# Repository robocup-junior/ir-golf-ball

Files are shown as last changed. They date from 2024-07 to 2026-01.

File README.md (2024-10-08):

# IR golf ball

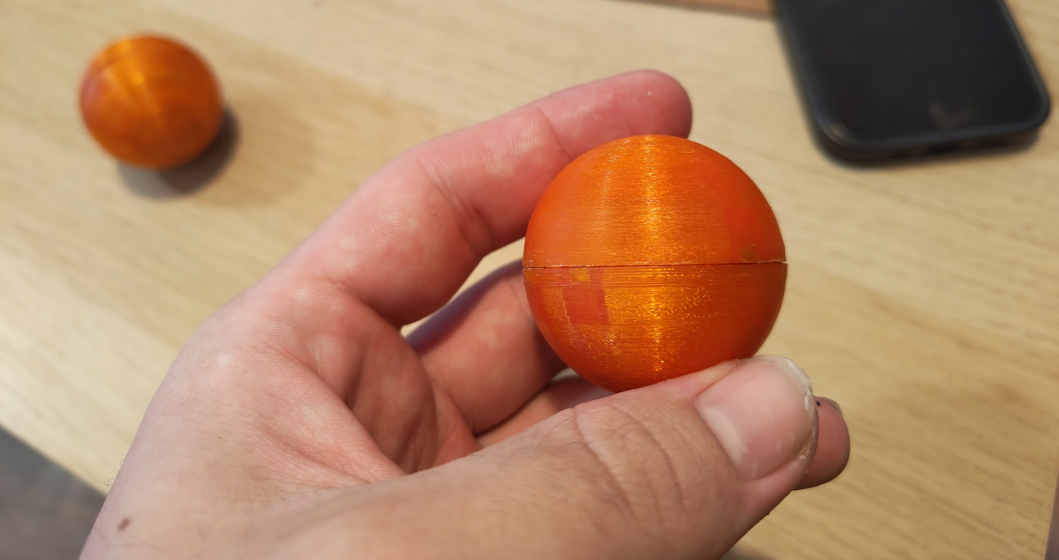
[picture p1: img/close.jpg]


# What / Why it is?
A golf size ball emiting IR light powered by 18350 Li-Ion battery with 40khz modulation (8 pulzes of 40khz then off with period of 1.2khz)

# How to get it?

## Buy it and suport us
You will be able to buy it soon from many places, for now we are taking preorders [here](https://docs.google.com/forms/d/e/1FAIpQLSeDNluafNvnX1WBIk5zJzcXsfOrKENFUOebmqeOT6po7Bbjzg/viewform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) cost is 20$ per ball build without battery

## Make it your self
## Step 1: Get all materials
You will be able to order kit from us or you can source all neaded components by your self.
### 1. Flex PCB
We recomend to order flexPCB from eather JLCPCB or PCBWAY, both do have sponsorship programs so you might be able to get it for free. Depending on your buget and skill set also think about ordering stencil (all componentc are posible to solder by hand soledring but it is easier to do it with stencil)

https://www.pcbway.com/sponsor.html
https://jlcpcb.com/help/article/how-to-apply-for-free-pcb
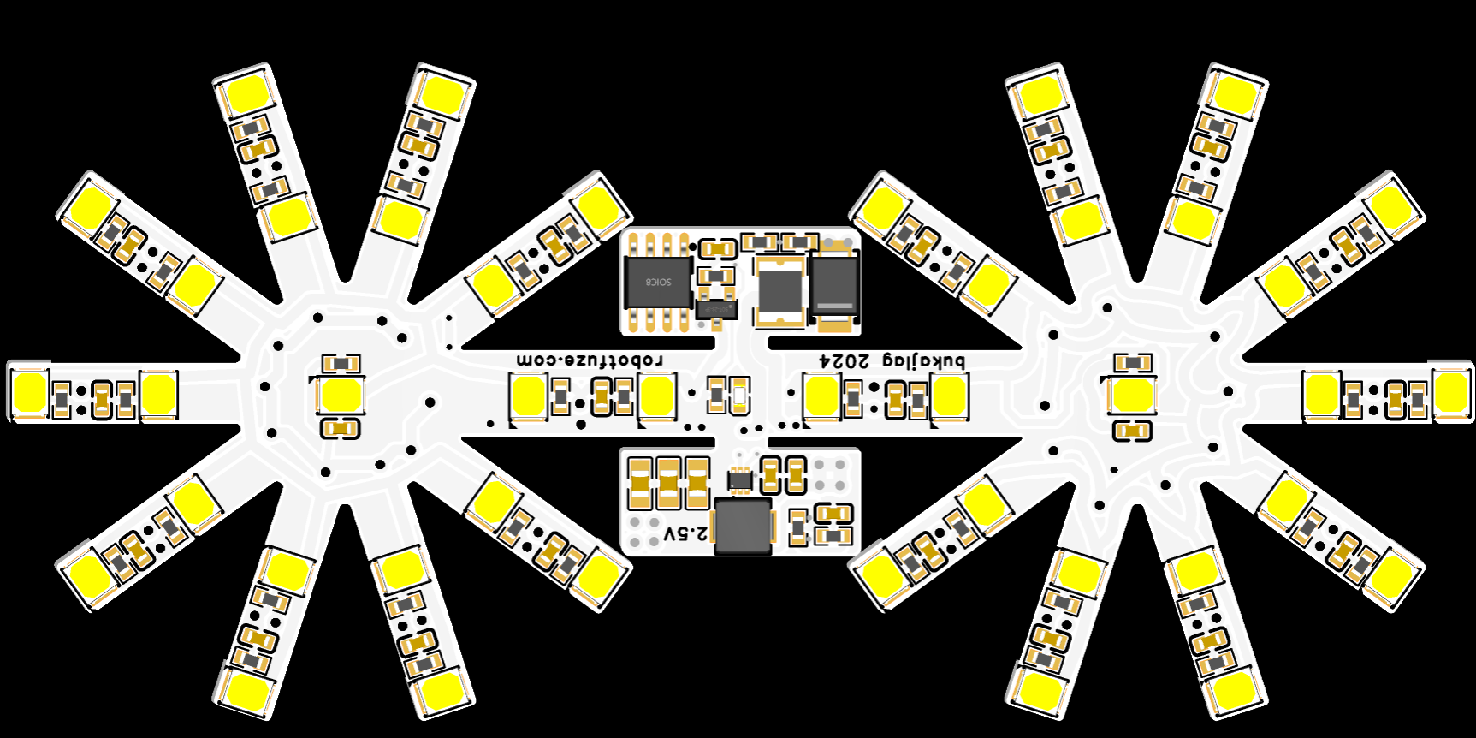
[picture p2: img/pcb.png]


All gerber files are in this repo.

### 2. Electrical components
<table>
  <thead>
    <tr>
      <th>Image</th>
      <th>Quantity</th>
      <th>Comment</th>
      <th>Footprint</th>
      <th>Value</th>
      <th>Manufacturer Part</th>
    </tr>
  </thead>
  <tbody>
    <tr>
      <td></td>
      <td>24</td>
      <td>22uF</td>
      <td>C0603</td>
      <td>22uF</td>
      <td>GRM188R60J226MEA0D</td>
    </tr>
    <tr>
      <td></td>
      <td>3</td>
      <td>47uF</td>
      <td>C0805</td>
      <td>47uF</td>
      <td>C2012X5R1A476MTJ00E</td>
    </tr>
    <tr>
      <td></td>
      <td>1</td>
      <td>4.7nF</td>
      <td>C0603</td>
      <td>4.7nF</td>
      <td>CC0603KRX7R9BB472</td>
    </tr>
    <tr>
      <td></td>
      <td>1</td>
      <td>120pF</td>
      <td>C0603</td>
      <td>120pF</td>
      <td>CL10C121JB8NNNC</td>
    </tr>
    <tr>
      <td></td>
      <td>1</td>
      <td>SS1045-SMB</td>
      <td>SMB_L4.4-W3.6-LS5.3-RD</td>
      <td></td>
      <td>SS1045-SMB</td>
    </tr>
    <tr>
      <td></td>
      <td>1</td>
      <td>220nH</td>
      <td>IND-SMD_L4.1-W4.1</td>
      <td>220nH</td>
      <td>IHLP1616BZERR22M01</td>
    </tr>
    <tr>
      <td></td>
      <td>42</td>
      <td>XL-2835IR-T202</td>
      <td>SMD2835</td>
      <td></td>
      <td>XL-2835IR-T202</td>
    </tr>
    <tr>
      <td></td>
      <td>1</td>
      <td>XL-1608SURC-06</td>
      <td>LED0603</td>
      <td></td>
      <td>XL-1608SURC-06</td>
    </tr>
    <tr>
      <td></td>
      <td>1</td>
      <td>AP3404</td>
      <td>SOT-23-3</td>
      <td></td>
      <td>AP3404</td>
    </tr>
    <tr>
      <td></td>
      <td>42</td>
      <td>10Ω</td>
      <td>R0603</td>
      <td>10Ω</td>
      <td>0603WAF100JT5E</td>
    </tr>
    <tr>
      <td></td>
      <td>3</td>
      <td>10k</td>
      <td>R0603</td>
      <td>10k</td>
      <td>RC0603FR-0710KL</td>
    </tr>
    <tr>
      <td></td>
      <td>1</td>
      <td>316kΩ</td>
      <td>R0603</td>
      <td>316kΩ</td>
      <td>RC0603FR-07316KL</td>
    </tr>
    <tr>
      <td></td>
      <td>1</td>
      <td>100kΩ</td>
      <td>R0603</td>
      <td>100kΩ</td>
      <td>RC0603FR-07100KL</td>
    </tr>
    <tr>
      <td></td>
      <td>1</td>
      <td>100Ω</td>
      <td>R0603</td>
      <td>100Ω</td>
      <td>0603WAJ0101T5E</td>
    </tr>
    <tr>
      <td></td>
      <td>1</td>
      <td>ATTINY202-SSNR</td>
      <td>SOIC-8</td>
      <td></td>
      <td>ATTINY202-SSNR</td>
    </tr>
    <tr>
      <td></td>
      <td>1</td>
      <td>TPS62A06DRLR</td>
      <td>SOT-563-6</td>
      <td></td>
      <td>TPS62A06DRLR</td>
    </tr>
    <tr>
      <td></td>
      <td>1</td>
      <td>1812L400/12GR</td>
      <td>F1812</td>
      <td></td>
      <td>1812L400/12GR</td>
    </tr>
  </tbody>
</table>

We recomend ordering from LCSC but you can find all the componets on other sites as well (Mouser,Digikey...). For finding best suplier for you, we recomend using https://octopart.com/ and checking out list of eqvivalent componts (TODO list of eqvivalent components and selection criterias)

### 3. Mechanical components
#### Filament
Shells are 3D printed, after lot of testing we found out that best option in general is using [PCTG](https://shop.spectrumfilaments.com/product-eng-1414-Filament-Spectrum-Premium-PCTG-1-75mm-PURE-ORANGE-1kg-RAL-2004.html) for good optical properties/cheap/easy to print/mechanical properties similar to PC. But PC is also posible to use.

#### Magnets
For magnets we are using 6 [6mm*5mm](https://www.unimagnet.cz/neodymovy-magnet-kotouc-6-mm-v-5-mm-sila-1-2-kg_z323/) N42 neodimium magnets. 

#### Brass 
For ball balancing we are using 6mm brass rod cuted into 6*5mm peaceas. We chose brass rod because it is really easy to find and it is cheap it has high density and it is not toxick.

#### Glue
Any superglue will work fine

### 4. Battery
We are using 18350 Li-Ion battery. We recomend capacity ranging from 1100mAh to 1200mAh (for balance reasons). It schold be easy to find in your local vape shop or battery store. Dont forget to get charger if you dont have one.

## Step 2: Print 3D shells
You can find stl files as well as sliced model in prushaslicer in 3d in this repo. Main thing to look for is to use enought of separation distance for suports (0.35mm) and to set temperature of bad to 100 C and nozle to 250 C.
Also print counterwight for balance and fill it with solder.

## Step 3: Asemble PCBs
While your 3d printer is working you can asemble PCBs. It can be done by hand but stencil is more convinient. We recomend to place coil as last component so you will be able to rework regulator solder joints if neaded after reflow.
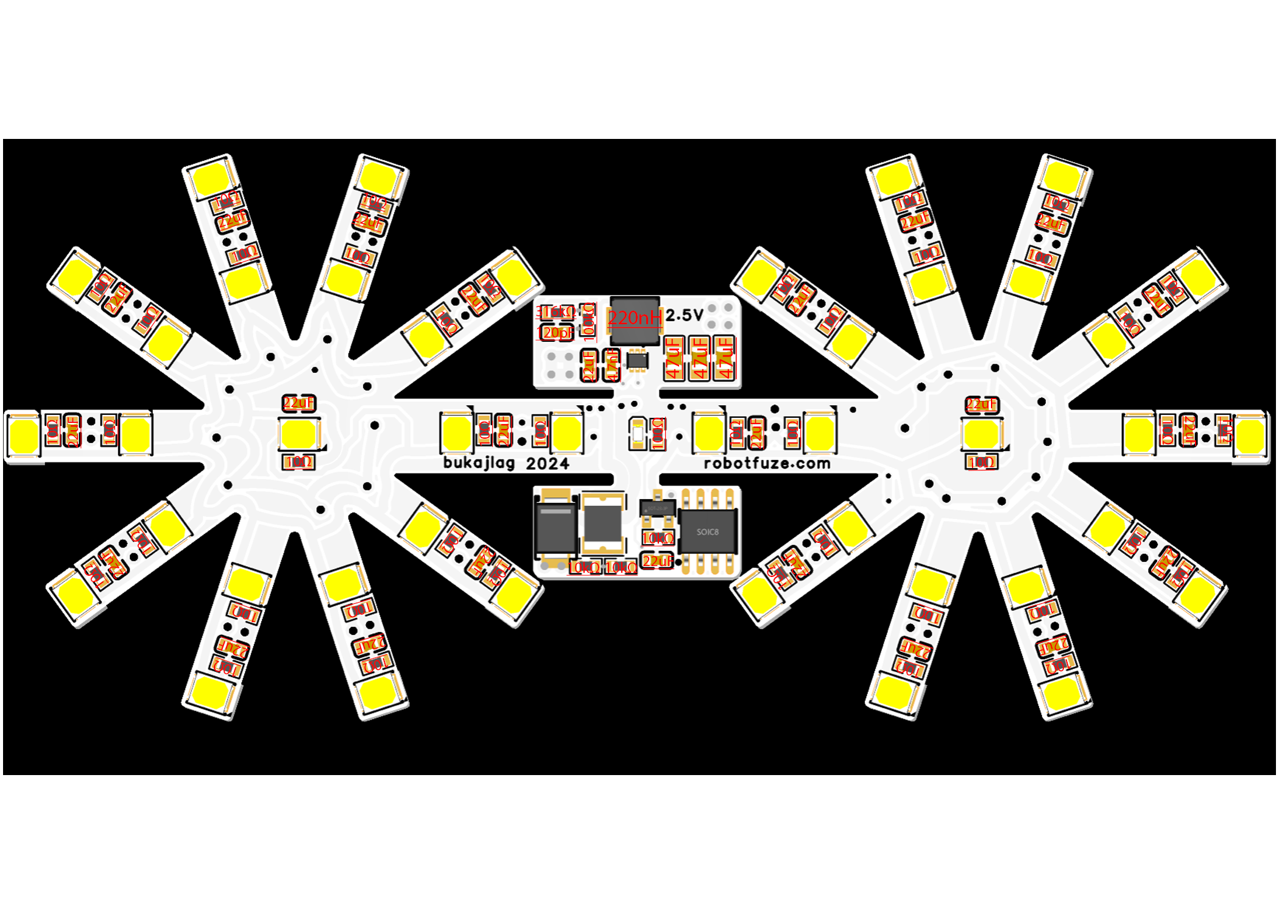
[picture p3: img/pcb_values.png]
pcb_values


## Step 4: Program AtTiny
This step is not neaded when you did buy a kit from us. 
The best way to aproach this is to watch this video: https://www.youtube.com/watch?v=AL9vK_xMt4E
and upload code as mention in the video. Dont forget to contect 3.3V to 2.5V trace when programing so UDPI voltages do match.

Also you schold test your PCB by using baterry if all LEDs are on.
TODO make video how to do it for our PCB

## Step 5: Cut brass rod
Now you nead to cut that 6mm btass rod into 5mm pieces, you will nead 12 of them. 

## Step 6: Insert magnets and brass rods into shells
Now you will nead to insert magnets and brass rods into 3D printed shells and glue it in using superglue. And wait till it will dry.

## Step 7: Insert PCB
Insert PCB into a 3D printed schells and make shure that baterry fits corectly. You can regulate contact of batery with PCB by adding or removing solder from battery contact pads that are on the PCB.

## Step 8: Test
Test your ball if it glows using your mobile phone.
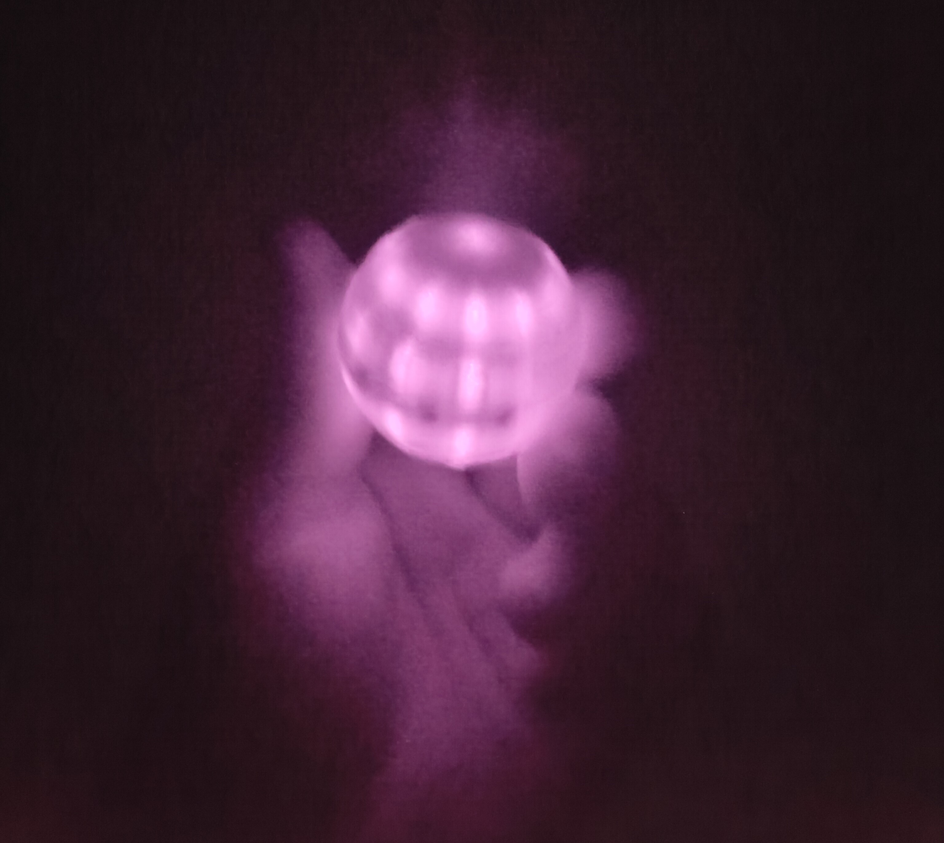
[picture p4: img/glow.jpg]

The end (:

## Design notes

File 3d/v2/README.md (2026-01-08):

# IR-Golf-Ball 3D Model v2

## What's Changed?
- You can assemble it without superglue!
- Easy battery change. The inner weight stays in the core when you take off one of the shells. 
- Uses M5x16mm set screws for counter weight. Easy procurement. 
- Calculated balance on CAD

## Parts List

| Item | Material | QTY | Note |
|---|---|---|---|
| Spacer M2x10mm | SUS304 | 2 | |
| M2x16mm Self-Tapping Screw | Carbon Steel | 2 | |
| M2x10mm Hex Socket Cap Screw (DIN912) | SUS304 | 4 | |
| 4mm Metal Ball | SUS304 | 26 | |
| M5x16mm Set Screw (DIN916) | SUS304 | 2 | |
| PCB | N/A | 1 | No Change from v1 |
| LiPo Cell 18360 | N/A | 1 | No Change from v1 |
| 3D Printed Ball Shell | PCTG | 2 | No Change from v1 |
| 3D Printed Inner Weight | PCTG/PETG | 2 | |
| 3D Printed Counter Weight | PCTG/PETG | 1 | |

## How to Assemble 
*Only explains differences from v1. Please follow v1 assembly instructions for the rest

### Counter Weight
Insert two M5x16mm set screws into the 3D-printed counter weight from each side.
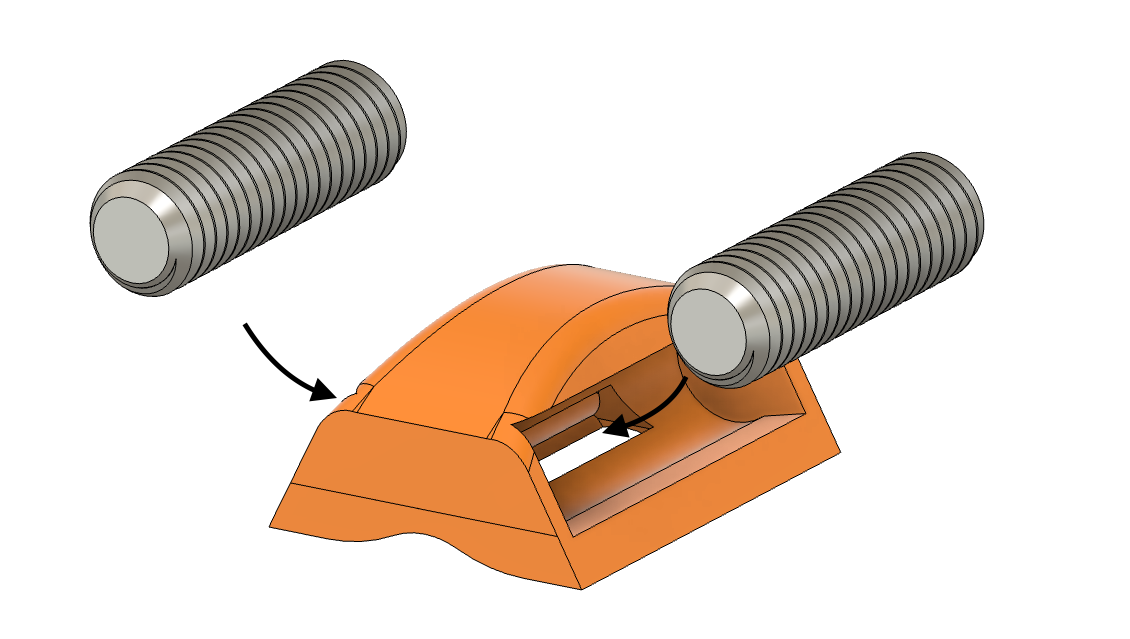
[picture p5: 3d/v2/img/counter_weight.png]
Assemblying Counter Weight


### Inner Weight
Place 4mm metal balls on the 3D-printed inner weight and gently push them into the holes one by one. Some holes require two balls in a row. Repeat for both inner weights.
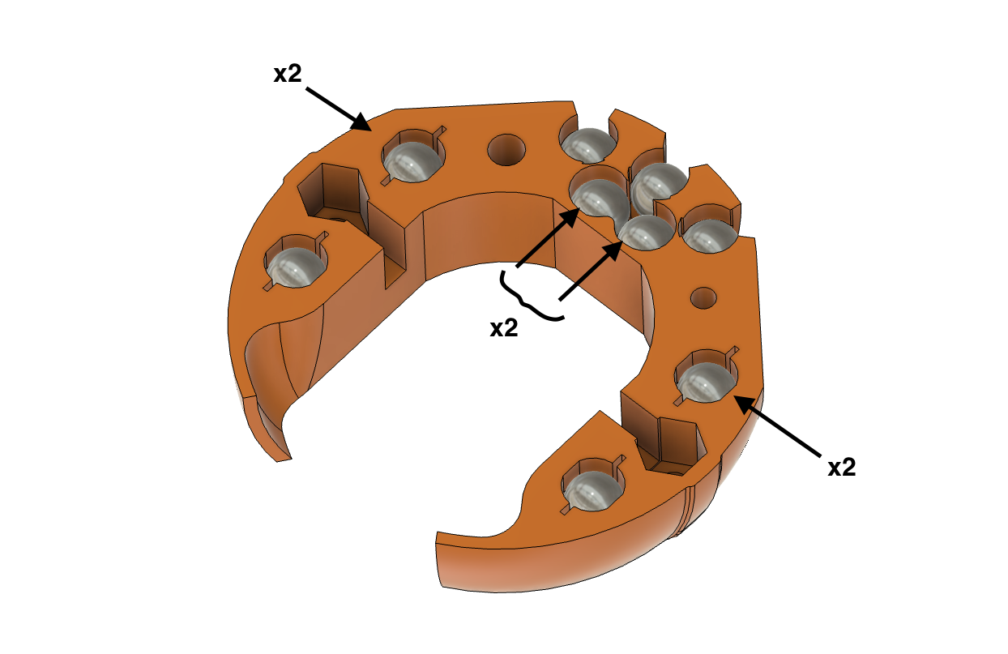
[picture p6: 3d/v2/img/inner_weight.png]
Insert balls into inner weight

  
Place two 2mm spacers on one of the inner weights and put the other one on top. Fix them with two M2 self-tapping screws. 
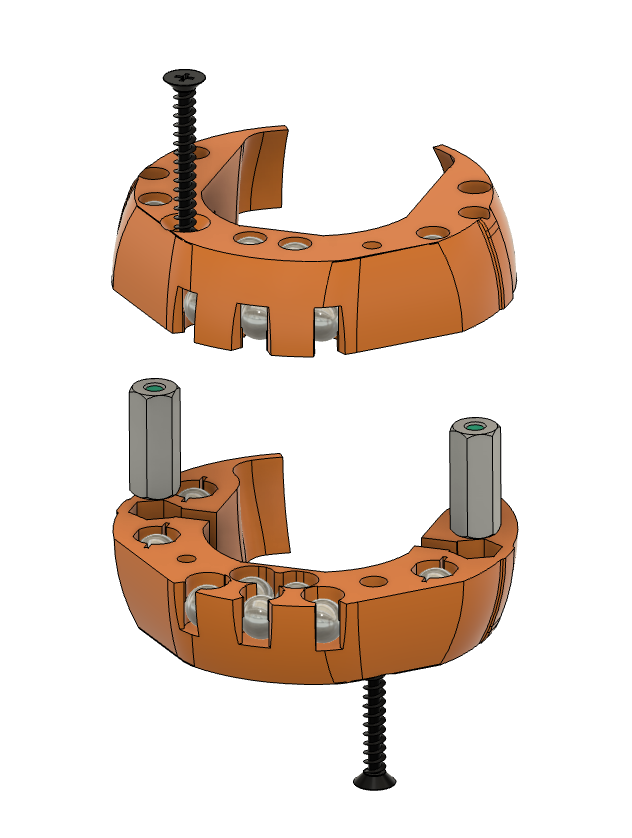
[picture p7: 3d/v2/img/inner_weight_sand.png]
Assembly inner weight


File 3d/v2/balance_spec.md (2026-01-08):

# IR Ball v2 Balance Report

### Basic Properties

| Property | Value |
|---|---|
| Mass | 57.950 g |
| Center of Mass | (0.007, -0.004, -0.386) mm |
| CoM Eccentricity | 0.386 mm |

### Inertia Tensor at Center of Mass (g·mm²)

$$
\mathbf{I}_{CM} = \begin{pmatrix}
8869.184 & 0.440 & -4.100 \\
0.440 & 8864.378 & 2.508 \\
-4.100 & 2.508 & 8816.923
\end{pmatrix}
$$

### Principal Moments of Inertia

| Principal Axis | Value (g·mm²) |
|---|---|
| I₁ (min) | 8816.469 |
| I₂ (mid) | 8864.500 |
| I₃ (max) | 8869.516 |

### Quality Metrics

| Metric | Value |
|---|---|
| Moment Difference (I₃/I₁ - 1) | 0.60% |
| Spread (I₃ - I₁) | 53.0 g·mm² |

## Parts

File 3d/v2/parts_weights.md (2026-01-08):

To calculate the balance of the ball, here is the list of part weights measured with actual parts.

# Parts Weights
| Item | Material | Mass | Note |
|---|---|---|---|
| Spacer M2x10mm | SUS304 | 0.841g | |
| M2x16mm Self-Tapping Screw | Carbon Steel | 0.239g | |
| M2x10mm Hex Socket Cap Screw (DIN912) | SUS304 | 0.285g | |
| 4mm Metal Ball | SUS304 | 0.253g | Diameter was 3.97mm |
| M5x16mm Set Screw (DIN916) | SUS304 | 1.63g  | |
| PCB | N/A | | Battery terminals soldered |
| LiPo Cell 18360 | N/A | | Vapcell 18350 M11 V2.0 1100mAh |
| 3D Printed Ball Shell* | PCTG | 5.90g  | |
| 3D Printed Inner Weight* | PCTG/PETG | 3.00g  | |
| 3D Printed Counter Weight* | PCTG/PETG | 0.78g  | |

# Weight Measurement Methodology

Randomly pick 10 pieces of an item from a bag and measure with a calibrated precision scale. Divide the measured weight by 10. Repeat the procedure with the remaining parts 5–15 times depending on the total quantity, then remove the minimum and maximum values and take the median of the rest. Use 3 significant figures.

__Weight scale__: Vibra DJ-150 (Minimum unit: 0.01g, calibrated with calibration weights)

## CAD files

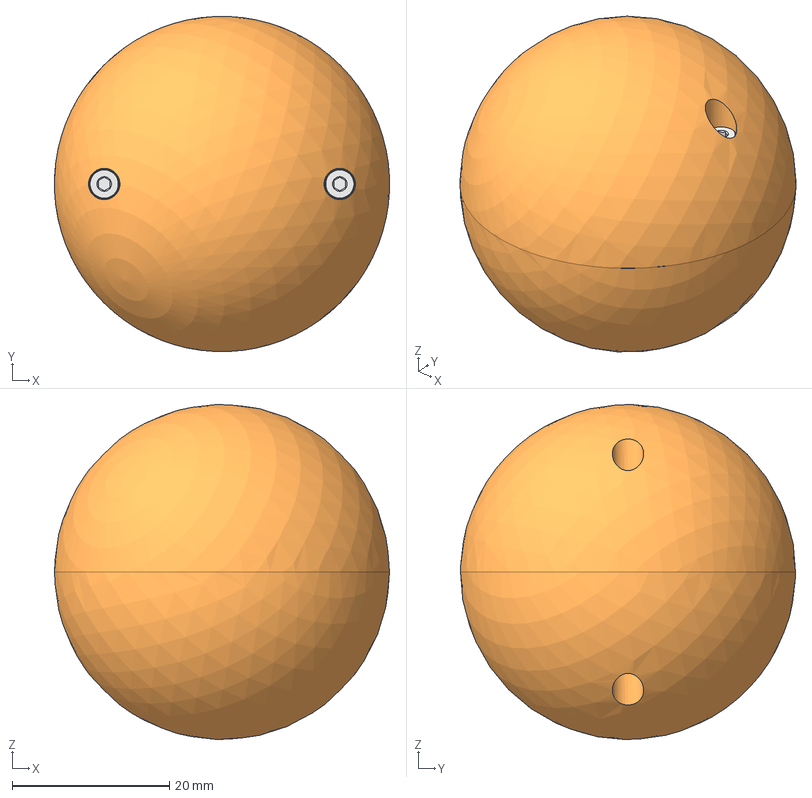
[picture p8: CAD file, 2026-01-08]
3d/v2/Assembly_v2.step
42.7 x 42.7 x 42.7 mm
shell_2025 v94 (1)_shell x 2
96415K57_Corrosion-Resistant 316 Stainless Steel Ball x 26
91290A017_Alloy Steel Socket Head Screw x 4
Board
Board (1)
92605A239_Stainless Steel Flat-Tip Set Screw x 2
90485A417_Stainless Steel Flat Head Thread-Forming Screws for Plastic x 2

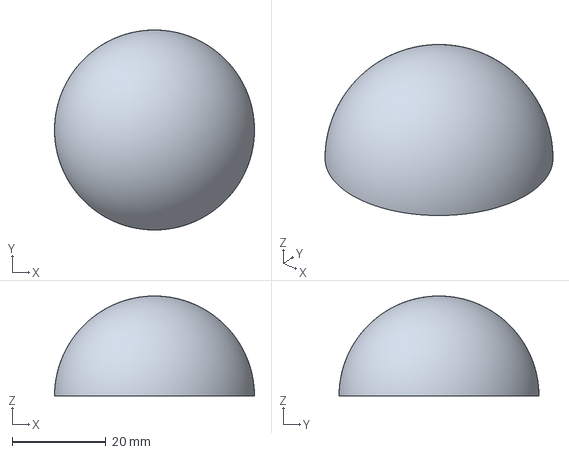
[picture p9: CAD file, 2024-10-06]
3d/ir_golf_ball.3mf
42.7 x 42.7 x 21.3 mm

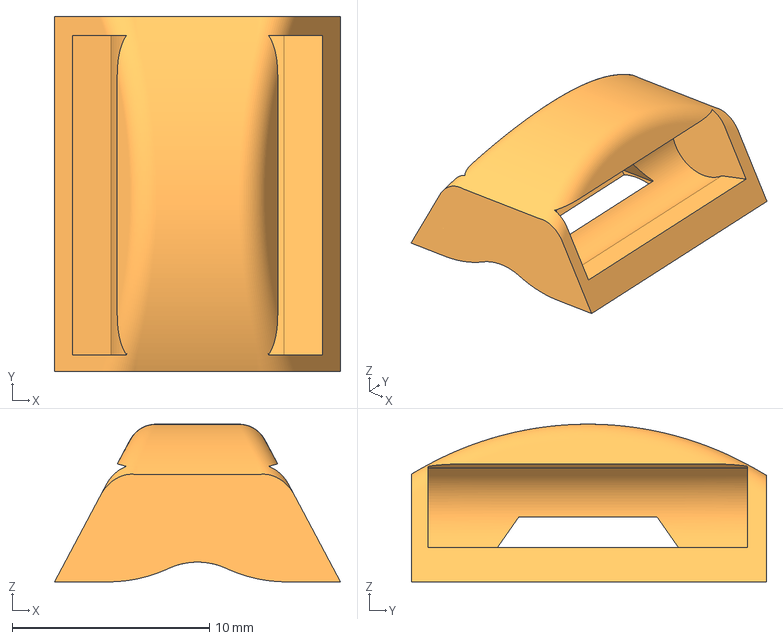
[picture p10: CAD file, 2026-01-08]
3d/v2/Counter_weight_v2.3mf
14.5 x 18.0 x 8.00 mm

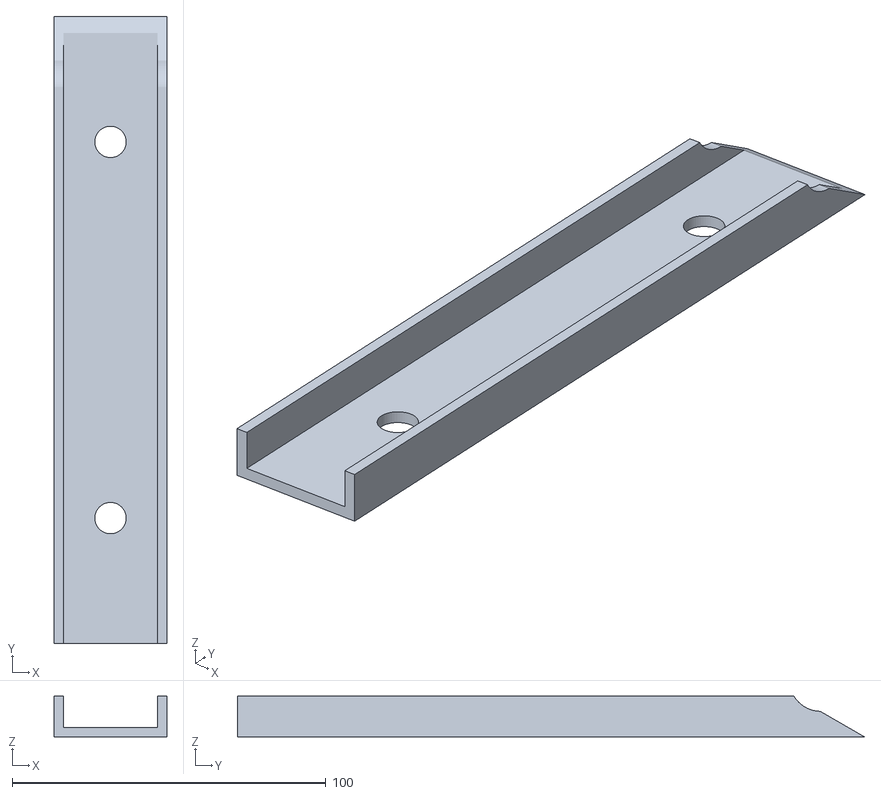
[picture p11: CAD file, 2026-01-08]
balance_evaluation/slope_top.stl
36.0 x 200.0 x 13.0

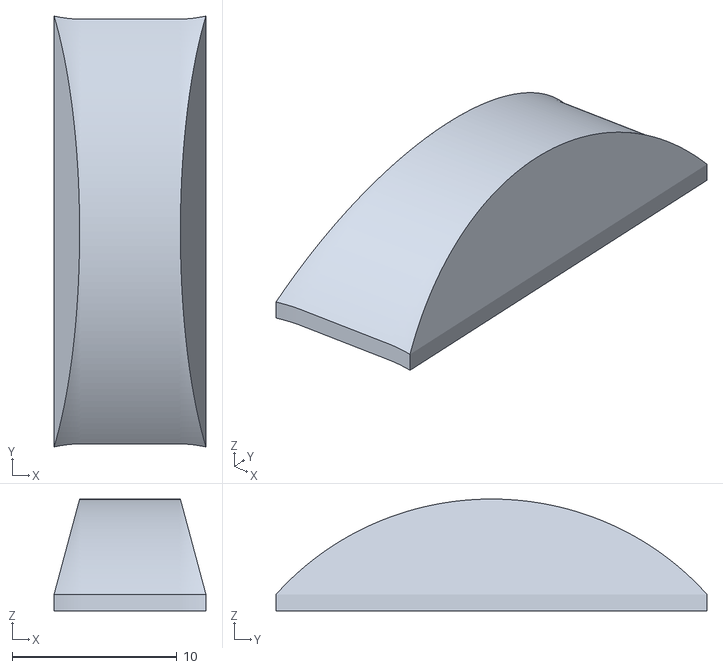
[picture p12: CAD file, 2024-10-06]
3d/balance.stl
9.23 x 26.2 x 6.80

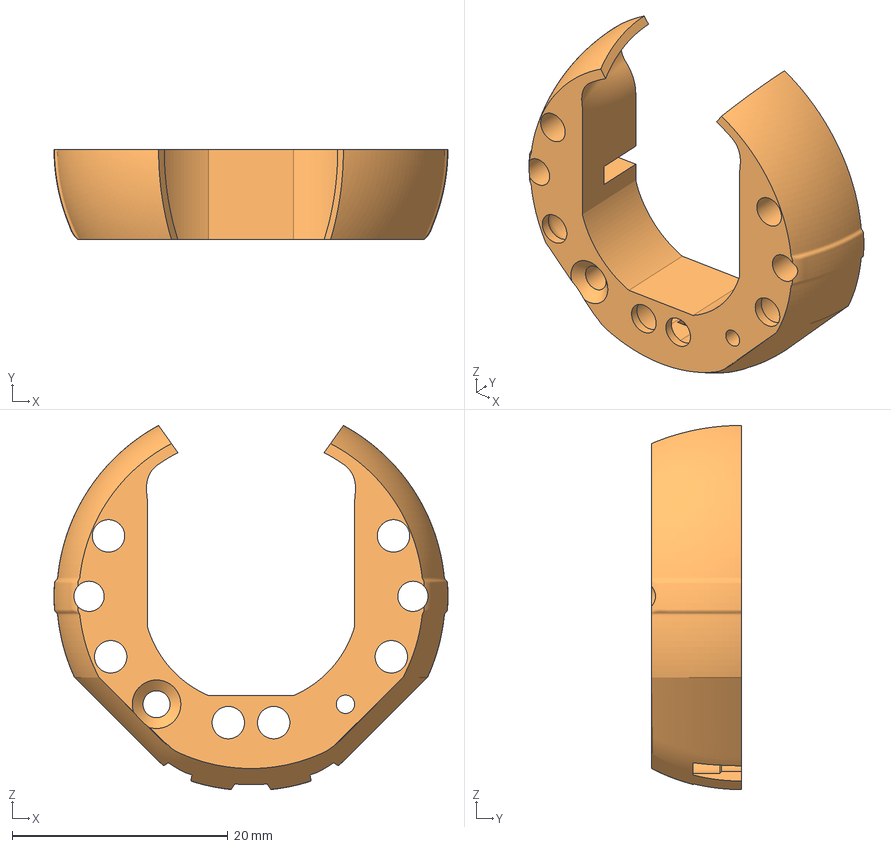
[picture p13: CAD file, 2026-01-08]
3d/v2/inner_weight_v2.3mf
36.5 x 8.34 x 33.7 mm

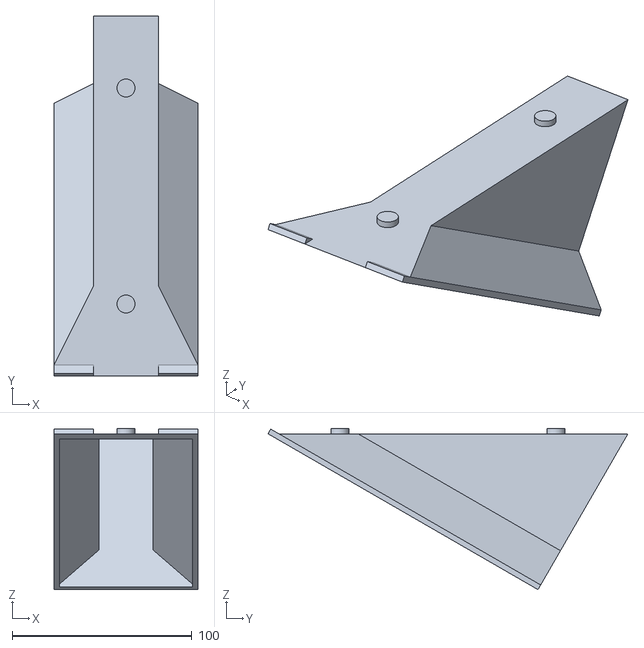
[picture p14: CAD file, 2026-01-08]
balance_evaluation/slope_base.stl
80.0 x 200.0 x 89.6

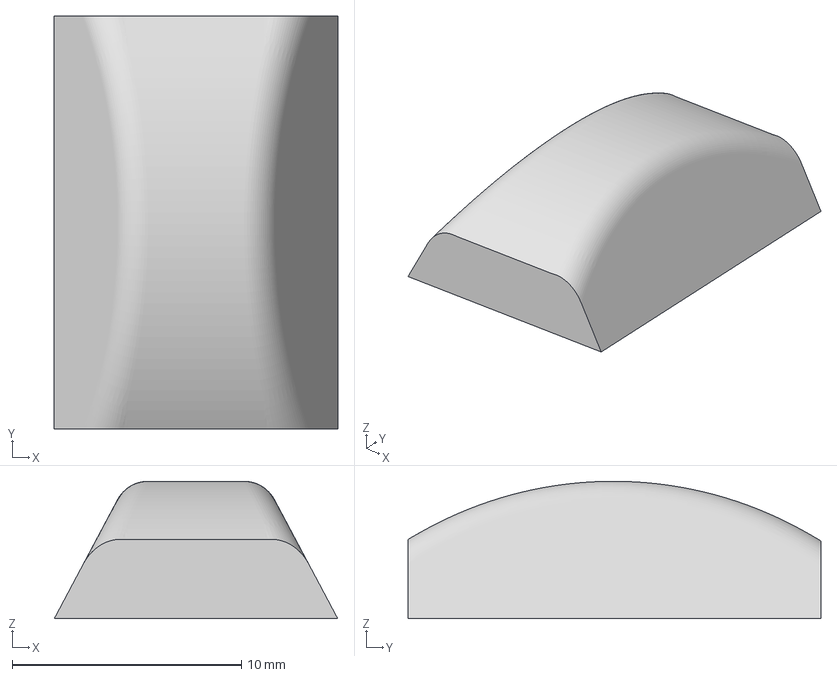
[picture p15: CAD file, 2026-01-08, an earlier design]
3d/v1/Counter_weight.3mf
12.4 x 18.0 x 6.00 mm

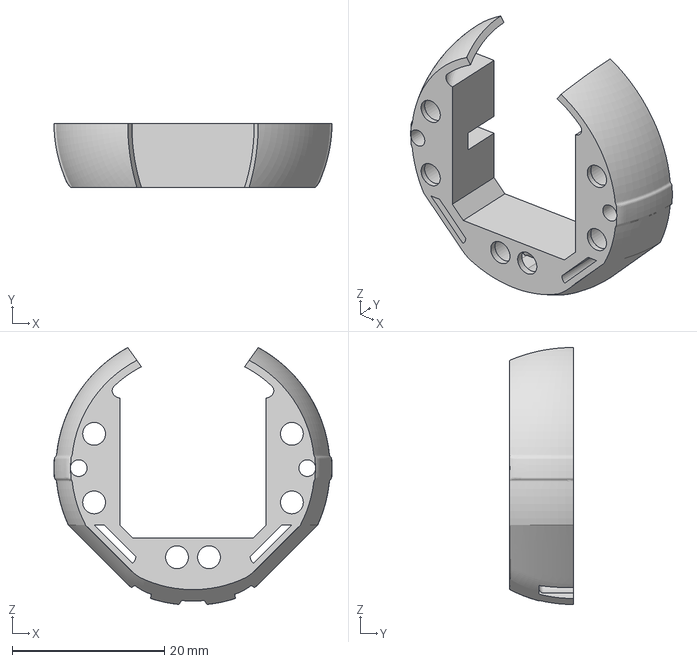
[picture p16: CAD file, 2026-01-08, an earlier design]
3d/v1/iner_screws.3mf
36.5 x 8.34 x 33.7 mm

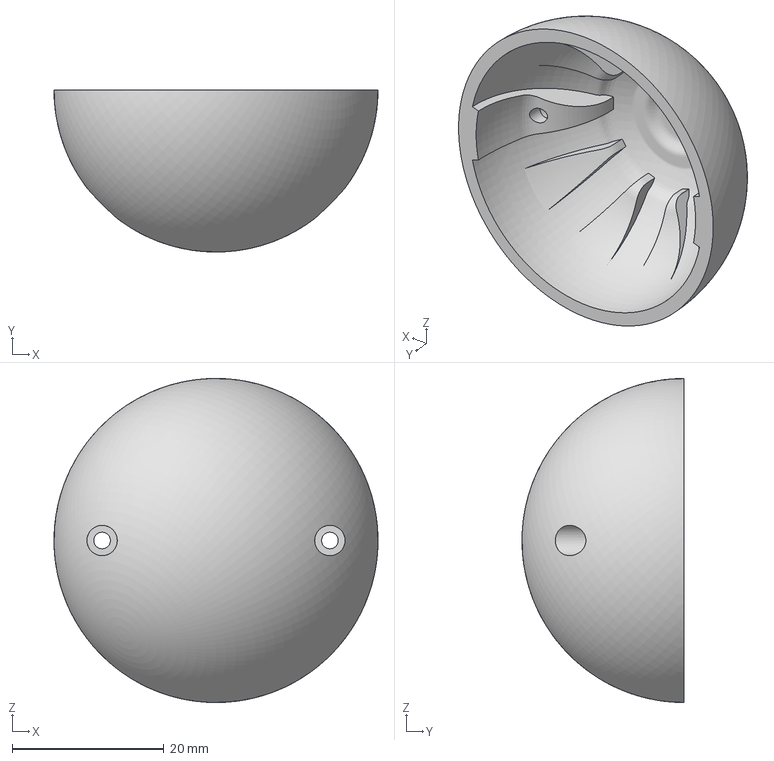
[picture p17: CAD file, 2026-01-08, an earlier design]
3d/v1/shell_screws.3mf
42.7 x 21.3 x 42.7 mm

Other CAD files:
3d/ir_golf_ball.stl

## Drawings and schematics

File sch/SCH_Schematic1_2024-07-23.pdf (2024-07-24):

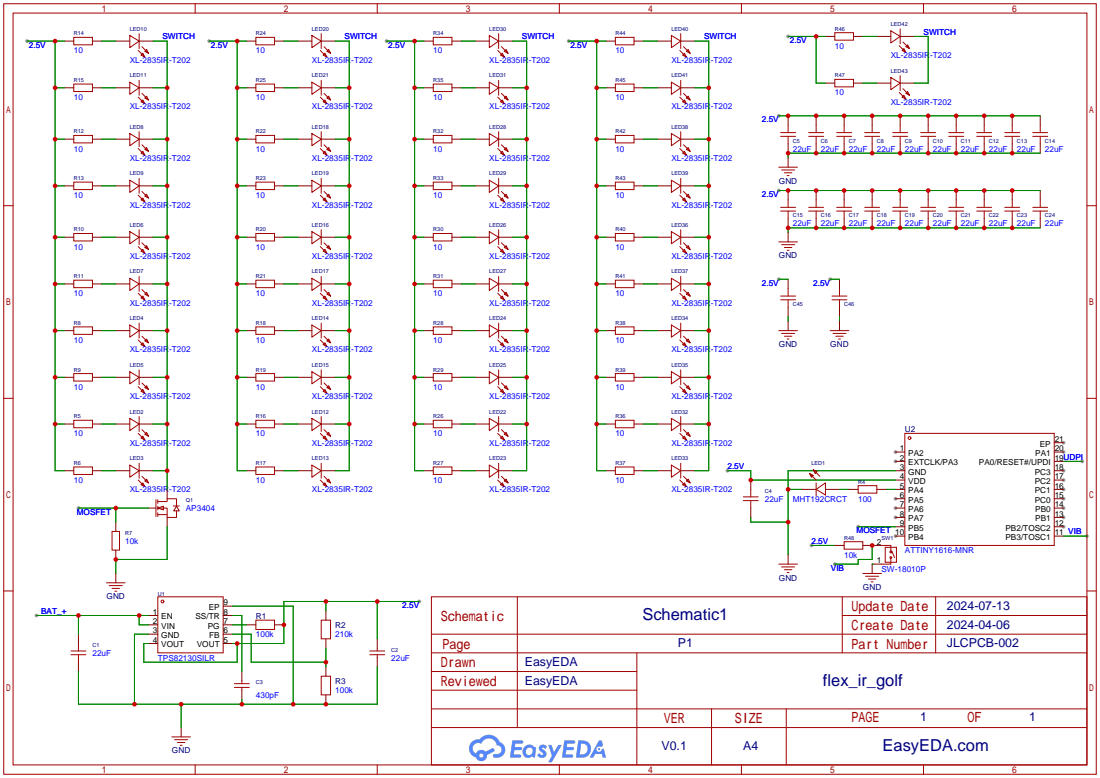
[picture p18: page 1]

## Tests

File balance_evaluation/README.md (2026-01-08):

# How to Measure the Balance: Deriving Principal Moments of Inertia from Inertia Tensor

The balance of the ball is important since if it's not balanced, the ball does not roll straight. 
In this document, we discuss how to evaluate the balance of the ball from logical and physical perspectives. 

As preparation, measure the weight of each part and set the density based on the volume of objects in Autodesk Fusion. 
By left-clicking on Project -> Properties, you can see the inertia tensor as `Moment of Inertia at Center of Mass (g mm^2)`

The inertia tensor of a rigid body is represented as a 3×3 symmetric matrix:

$$
\mathbf{I} = \begin{pmatrix}
I_{xx} & I_{xy} & I_{xz} \\
I_{xy} & I_{yy} & I_{yz} \\
I_{xz} & I_{yz} & I_{zz}
\end{pmatrix}
$$

Where:
- **Diagonal components** $I_{xx}, I_{yy}, I_{zz}$: Moments of inertia about each axis
- **Off-diagonal components** $I_{xy}, I_{xz}, I_{yz}$: Products of inertia

## 2. Principal Moments of Inertia (Eigenvalue Problem)

The principal moments of inertia $I_1, I_2, I_3$ are obtained as the **eigenvalues** of the inertia tensor.

Eigenvalue equation:

$$
\det(\mathbf{I} - \lambda \mathbf{E}) = 0
$$

Expanding yields the **characteristic equation** (cubic equation):

$$
\lambda^3 - \text{tr}(\mathbf{I})\lambda^2 + \frac{1}{2}\left[(\text{tr}\mathbf{I})^2 - \text{tr}(\mathbf{I}^2)\right]\lambda - \det(\mathbf{I}) = 0
$$

Or more explicitly:

$$
\begin{vmatrix}
I_{xx} - \lambda & I_{xy} & I_{xz} \\
I_{xy} & I_{yy} - \lambda & I_{yz} \\
I_{xz} & I_{yz} & I_{zz} - \lambda
\end{vmatrix} = 0
$$

The three real roots $\lambda_1, \lambda_2, \lambda_3$ of this cubic equation are the principal moments of inertia:

$$
I_1 = \lambda_{\min}, \quad I_2 = \lambda_{\text{mid}}, \quad I_3 = \lambda_{\max}
$$

## 3. Coefficients of the Characteristic Equation

The characteristic equation can be written as:

$$
\lambda^3 - A\lambda^2 + B\lambda - C = 0
$$

Where:

$$
A = I_{xx} + I_{yy} + I_{zz} = \text{tr}(\mathbf{I})
$$

$$
B = I_{xx}I_{yy} + I_{yy}I_{zz} + I_{zz}I_{xx} - I_{xy}^2 - I_{yz}^2 - I_{xz}^2
$$

$$
C = \det(\mathbf{I})
$$

## 4. Principal Moment Difference (Isotropy Metrics)

Once the principal moments are obtained, the deviation from spherical symmetry can be evaluated using the following metrics:

### 4.1 Moment Difference

$$
\varepsilon = \frac{I_{\max} - I_{\min}}{I_{\min}} \times 100\%
$$

Or equivalently:

$$
\varepsilon = \left(\frac{I_3}{I_1} - 1\right) \times 100\%
$$

**This Moment Difference should be as small as possible!**  
**Less difference means more equality of inertia on each axis, which makes the ball roll straighter!!**

### 4.2 Spread

$$
\Delta I = I_{\max} - I_{\min} = I_3 - I_1
$$

## (Reference) 5. Perfect Sphere Case

For a homogeneous perfect sphere:

$$
I_1 = I_2 = I_3 = \frac{2}{5}mr^2
$$

In this case:
- Moment difference $\varepsilon = 0\%$
- Spread $\Delta I = 0$
- The inertia tensor is diagonal (all off-diagonal components are zero)

## 6. Numerical Example
Let us calculate the Principal Moments of Inertia and Moment Difference by using the inertia tensor from v2 model.  

Input data:

$$
\mathbf{I}_{CM} = \begin{pmatrix}
8869.184 & 0.440 & -4.100 \\
0.440 & 8864.378 & 2.508 \\
-4.100 & 2.508 & 8816.923
\end{pmatrix}
$$

Eigenvalue calculation results:

| Principal Moment | Value (g·mm²) |
|---|---|
| $I_1$ (min) | 8816.469 |
| $I_2$ (mid) | 8864.500 |
| $I_3$ (max) | 8869.516 |

Moment difference:

$$
\varepsilon = \left(\frac{8869.516}{8816.469} - 1\right) \times 100\% = 0.60\%
$$

# Test the Balance in Real Environment
In addition to the logic above, evaluating the balance of the assembled ball in your hand is also important.

## Preparation
Print this model with your 3D printer. Any type of filament is fine. 
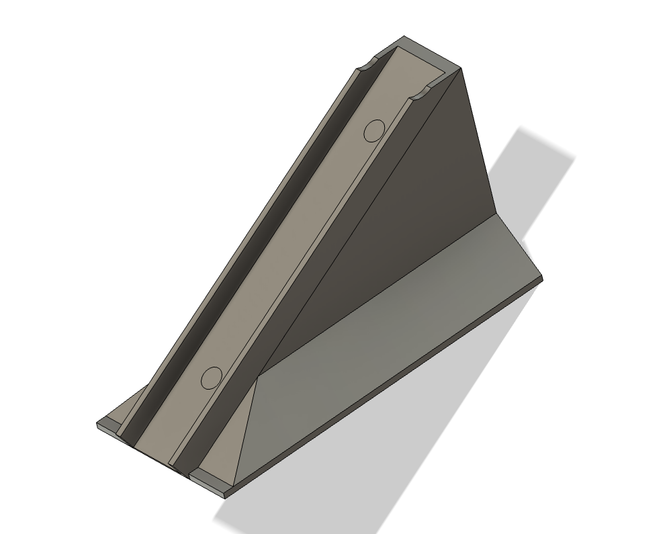
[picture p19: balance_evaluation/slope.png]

[slope_base.stl](./slope_base.stl)  
[slope_top.stl](./slope_top.stl)

Then, label each axis on the ball like this. The side where the counter weight is located should be labeled as `Y-`
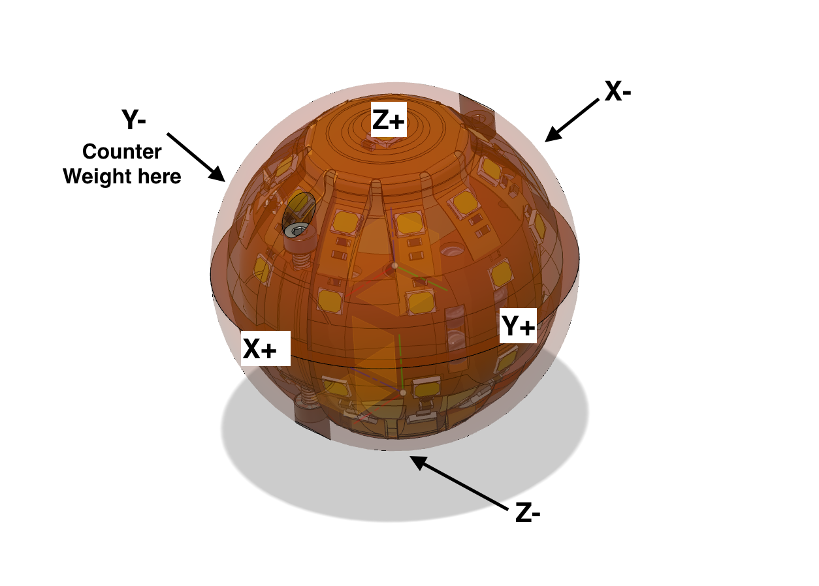
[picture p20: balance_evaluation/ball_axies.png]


## Test
Put the ball on the slope and roll it 6 times by:
1. Face `Z+` on top, `X-` on right towards the rolling direction (Ixx-CW)
2. Face `Z+` on top, `X+` on right towards the rolling direction (Ixx-CCW)
3. Face `Z+` on top, `Y-` on right towards the rolling direction (Iyy-CW)
4. Face `Z+` on top, `Y+` on right towards the rolling direction (Iyy-CCW)
5. Face `X+` on top, `Z-` on right towards the rolling direction (Izz-CW)
6. Face `X+` on top, `Z+` on right towards the rolling direction (Izz-CCW)

Then you can evaluate which axis has an uneven moment of inertia. 
If there is an unbalanced axis, the ball goes in the opposite direction when you compare CW and CCW. For instance, if the paths of `Ixx-CW` and `Ixx-CCW` go in opposite directions, either side of `X+` or `X-` is heavier or lighter and makes the ball unbalanced. 

Testing it on a flat and smooth surface is theoretically correct, but on rough carpet like a soccer field, small errors may not matter. So I recommend testing it on carpet and seeing how practical it is in RCJ.

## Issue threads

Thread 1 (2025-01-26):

Clarification on technical specifications of the IR-golf-ball

MarkV9, 2025-01-26:
Hello, as a friend of mine and me wanted to build a ball ourself we came up with some questions regarding the ball.

## Firmware
Is the firmware for the ball up to date? I was wondering if the modulation of the IR signal is implemented.

In the ball specifications of the RCJ, it states:

> Each 833-microsecond cycle of the modulation waveform shall comprise 8 carrier pulses at full intensity, followed (in turn) by 4 carrier pulses at 1/4 of full intensity, four pulses at 1/16 of full intensity and four pulses at 1/64 of full intensity, followed by a space (i.e., zero intensity) of about 346 microseconds.
[RCJ 2025 Soccer Rules: Ball Specification](https://robocup-junior.github.io/soccer-rules/2025-soccer-draft-rules/ball_specification.html)

However, as the AtTiny only uses `digitalWriteFast(3, HIGH);`, I am unsure how this modulation is implemented.
Am I missing some clever electronics, or is the code simply not up to date?

---

## Schematics
I believe the PDF in the *sch* directory is also outdated. It seems the PCB uses a 20-pin AtTiny1616, whereas the preview pictures show an 8-pin AtTiny202(?).

Could you please clarify these topics and update the outdated files?
Thank you in advance!

JakubGal, 2025-01-27:
Hello,
First of all we are happy that you are trying to build it your self

For the firmware, there is modulation change for 2026, there have already bean a lot of discussion on this topic but here is document on why it is happening:

https://docs.google.com/document/d/1udhcp6jrlTYNrfYHzZVJLbGYkSEPzJfAvasZTW9j--k/edit?usp=sharing

For the schematics, yes thanks for notifying us it is updated now (we are trying to use time as much as possible for some additional development so ball will be best it can be)

We are also planning to start distribution at latest in 28. February 2025 so if you want assembled one you will finally be able to get it. But we encourage building one your self, it is fun  :blush:

Thanks for asking

Closed 2025-02-02.

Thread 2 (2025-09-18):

Heartbeat causes interruption of IR signal

guenter-wo, 2025-09-18:
The heartbeat that flashes the red LED each 15 seconds pauses the IR signal for 100ms. This will likely confuse the ball detection code of the robots.
Suggest to avoid the delay(100) call. Code could look as follows:
old code:
```
      // 3) While still ACTIVE (and not forced off by battery), do a single quick blink every 15 s
      //    Only blink if the LED is currently LOW (i.e. not in battery-warning ON state)
      if ((now - lastBlinkMs >= 15000) && (digitalRead(LED_PIN) == LOW)) {
        digitalWriteFast(LED_PIN, HIGH);
        delay(100);                                               //****This call pauses the IR signal!!!****
        digitalWriteFast(LED_PIN, LOW);
        lastBlinkMs = now;
      }
```
Suggested new code:
 ```
     // 3) While still ACTIVE (and not forced off by battery), do a single quick blink every 15 s
      //    Only blink if the LED is currently LOW (i.e. not in battery-warning ON state)
      //    We do not use delay(100) here to allow IR pulses to continue
      if (now - lastBlinkMs >= 15000) {
        if (digitalRead(LED_PIN) == LOW) {
          digitalWriteFast(LED_PIN, HIGH);
        }
        else if (now - lastBlinkMs >= 15100) {
          digitalWriteFast(LED_PIN, LOW);
          lastBlinkMs = now;
        }
```

Closed 2025-09-20.

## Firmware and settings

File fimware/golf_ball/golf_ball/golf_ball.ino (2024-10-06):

long adc;
int loop_count = 0;
void setup() {
  pinMode(2, OUTPUT); //LED
  pinMode(3, OUTPUT); //MOSFET
  pinMode(4, INPUT); //ADC

  digitalWriteFast(2, LOW);
  digitalWriteFast(3, LOW);
}

void loop() {
  for (uint8_t i = 0; i < 8; i++) {
    digitalWriteFast(3, HIGH);
    delayMicroseconds(12);
    digitalWriteFast(3, LOW);
    delayMicroseconds(12);
  }

  //Takes aproximatli100uS

  adc += analogRead(4);
  if (loop_count == 1000) {
    adc = adc / 1000;

    if (adc < 660) {
      digitalWriteFast(2, HIGH);
      if (adc < 530) {
        while (true) {
          digitalWriteFast(2, HIGH);
          delay(100);
          digitalWriteFast(2, LOW);
          delay(1000);
        }
      }
    }
    else {
      digitalWriteFast(2, LOW);
    }
    loop_count = 0;
  }


  delayMicroseconds(550);


  loop_count++;
}
